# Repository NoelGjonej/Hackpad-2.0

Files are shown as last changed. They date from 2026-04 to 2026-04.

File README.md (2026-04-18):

# PCB Design



# Case Design



# XIAO Macropad — KMK Firmware
## Seeeduino XIAO · 6 Keys · EC11E Rotary Encoder · SSD1306 128x32 OLED

---

## Why KMK instead of QMK?

KMK runs on **CircuitPython** — there is no compiling, no toolchain, no flashing.
You just copy files onto the XIAO like a USB drive. Much easier for the XIAO.

---

## Key Layout

```
[ PREV  ] [ PLAY  ] [ NEXT  ]
[ COPY  ] [ PASTE ] [ SNIP  ]
                              Encoder CW  → Volume Up
                              Encoder CCW → Volume Down
                              Encoder Click → Mute / Unmute
```

| Key | Action |
|-----|---|
| Top-left  | ⏮ Previous Track |
| Top-mid | ▶ Play / Pause |
| Top-right | ⏭ Next Track |
| Bot-left  | Ctrl+C — Copy |
| Bot-mid | Ctrl+V — Paste |
| Bot-right | Win+Shift+S — Snipping Tool |
| Encoder CW | 🔊 Volume Up |
| Encoder CCW | 🔉 Volume Down |
| Encoder click | 🔇 Mute / Unmute toggle |

---

## Wiring

### Key Matrix (2 rows × 3 cols, COL2ROW diodes)

```
         COL0(D0)   COL1(D1)   COL2(D2)
ROW0(D3)   PREV       PLAY       NEXT
ROW1(D4)   COPY       PASTE      SNIP
```

Add a 1N4148 diode per switch — cathode (black band) toward the ROW pin.

### EC11E Encoder

| EC11E pin | XIAO pin | Function |
|---|---|---|
| CLK (A) | D7 | Rotation A |
| DT  (B) | D8 | Rotation B |
| SW | D6 | Click = Mute |
| GND | GND | Ground |

Add 10kΩ pull-up resistors on CLK and DT to 3.3V if you get jitter.

### SSD1306 OLED (I2C, 128×32)

| OLED pin | XIAO pin |
|---|---|
| SDA | D9  (SDA) |
| SCL | D10 (SCL) |
| VCC | 3.3V |
| GND | GND |

Default I2C address is 0x3C. If your OLED doesn't appear, try 0x3D in code.py.

---

## Setup Instructions

### Step 1 — Install CircuitPython on the XIAO

1. Download the CircuitPython UF2 for Seeeduino XIAO from:
   https://circuitpython.org/board/seeeduino_xiao/
   (download the latest stable .uf2 file)

2. Double-tap the RST pin on the XIAO — a drive called **XIAO-BOOT** appears on your PC.

3. Drag and drop the `.uf2` file onto that drive.
   The XIAO reboots and a new drive called **CIRCUITPY** appears.

### Step 2 — Install CircuitPython libraries

Download the CircuitPython Library Bundle from:
https://circuitpython.org/libraries

Unzip it. From the `lib/` folder inside, copy these folders/files
into the `lib/` folder on your **CIRCUITPY** drive:

```
adafruit_displayio_ssd1306.mpy
adafruit_display_text/
adafruit_imageload/
kmk/                          ← get this from https://github.com/KMKfw/kmk_firmware
```

To get KMK, download the zip from https://github.com/KMKfw/kmk_firmware
and copy the `kmk/` folder onto CIRCUITPY/lib/.

### Step 3 — Copy your code

Copy these two files from this folder onto the root of **CIRCUITPY**:

```
boot.py   → CIRCUITPY/boot.py
code.py   → CIRCUITPY/code.py
```

Your CIRCUITPY drive should look like:
```
CIRCUITPY/
├── boot.py
├── code.py
└── lib/
    ├── kmk/
    ├── adafruit_displayio_ssd1306.mpy
    ├── adafruit_display_text/
    └── adafruit_imageload/
```

### Step 4 — Done

The XIAO reboots automatically when you save files. Your macropad is ready.
No compiling, no flashing tools needed.

---

## Making changes

To change a key, open `code.py` in any text editor, edit the `keyboard.keymap` list,
and save. The XIAO reboots and picks up the change in a few seconds.

Common keycodes:
```python
KC.LCTL(KC.Z)     # Ctrl+Z  (undo)
KC.LCTL(KC.S)     # Ctrl+S  (save)
KC.LGUI(KC.L)     # Win+L   (lock screen)
KC.PSCR           # Print Screen
KC.TAB, KC.ESC, KC.ENT, KC.BSPC
KC.F1 ... KC.F12
```

---

## Troubleshooting

| Problem | Fix |
|---|-----|
| CIRCUITPY drive doesn't appear | Double-tap RST faster (within ~500ms) |
| Keys not working | Check diode direction — cathode (black band) toward row pin |
| Encoder jittery | Add 10kΩ pull-ups on CLK and DT to 3.3V |
| OLED blank | Check SDA/SCL wiring; try changing 0x3C to 0x3D in code.py |
| Error on boot | Connect to XIAO via serial (PuTTY / Thonny) to read the error message |

### Reading error messages (very useful for debugging)

Install **Thonny** (free Python IDE): https://thonny.org
Connect to the XIAO's serial port — it shows any Python errors live,
which makes debugging very easy.

---

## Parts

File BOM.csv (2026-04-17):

Name | Purpose | Quantity
0.91" display | Display volume | 1
XIAO RP2040 | Controll everything | 1
EC11E Rotary Encoder | Controll volume | 1
Key Switch | Skip/Play etc. | 6

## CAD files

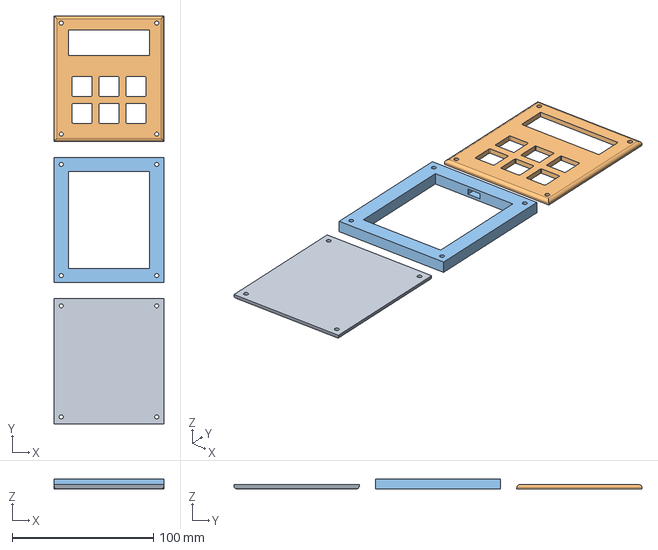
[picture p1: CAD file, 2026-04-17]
Hackpad 2.0.step
77.5 x 288.6 x 7.00 mm

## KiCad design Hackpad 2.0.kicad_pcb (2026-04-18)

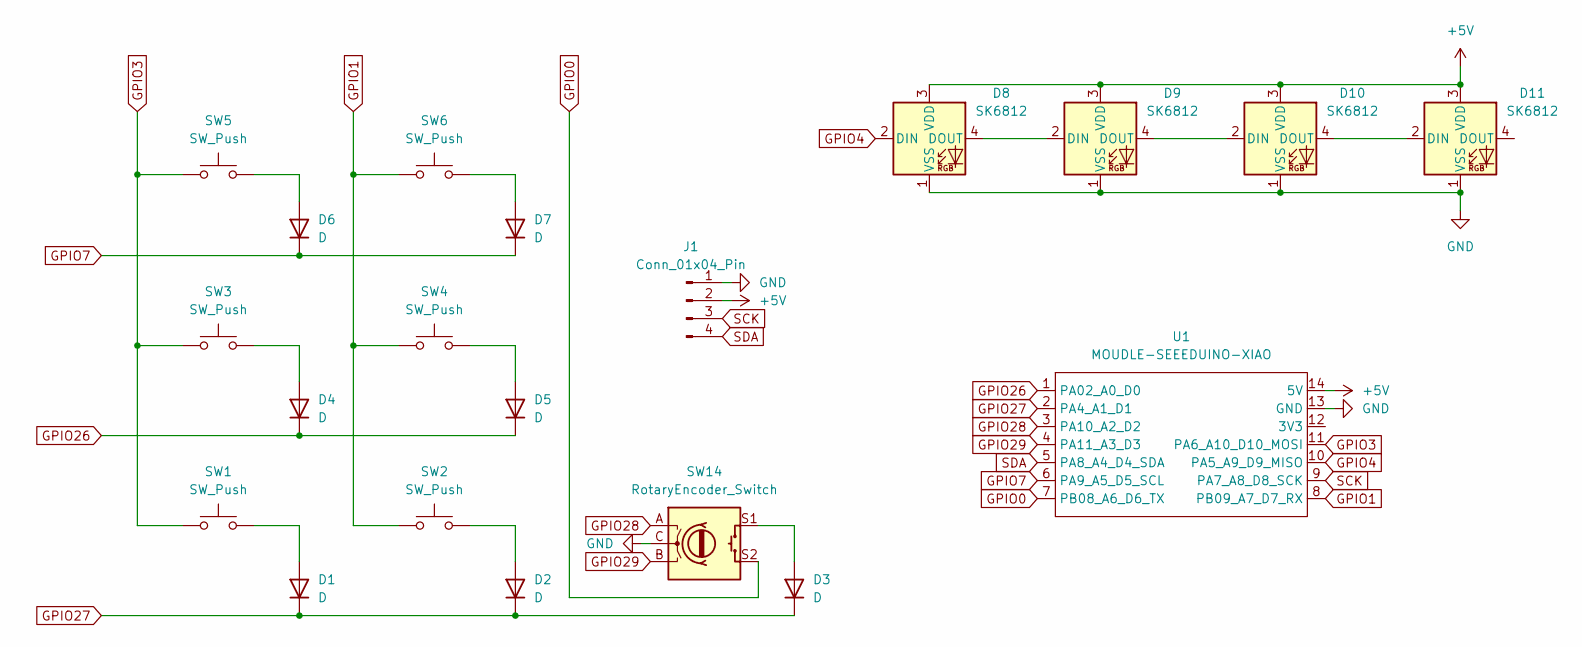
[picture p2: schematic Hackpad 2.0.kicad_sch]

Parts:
D1, D2, D3, D4, D5, D6, D7: D; D_DO-35_SOD27_P7.62mm_Horizontal
D8, D9, D10, D11: SK6812; LED_SK6812_PLCC4_5.0x5.0mm_P3.2mm
J1: Conn_01x04_Pin; PinSocket_1x04_P2.54mm_Vertical
SW1, SW2, SW3, SW4, SW5, SW6: SW_Push; SW_Cherry_MX_1.00u_PCB
SW14: RotaryEncoder_Switch; RotaryEncoder_Alps_EC11E-Switch_Vertical_H20mm
U1: MOUDLE-SEEEDUINO-XIAO; XIAO-Generic-Hybrid-14P-2.54-21X17.8MM

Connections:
+5V: D8.3 (VDD), D9.3 (VDD), D10.3 (VDD), D11.3 (VDD), J1.2, U1.14 (5V)
GND: D8.1 (VSS), D9.1 (VSS), D10.1 (VSS), D11.1 (VSS), J1.1, SW14.C, U1.13 (GND)
GPIO0: SW14.S2, U1.7 (PB08_A6_D6_TX)
GPIO1: SW2.1, SW4.1, SW6.1, U1.8 (PB09_A7_D7_RX)
GPIO3: SW1.1, SW3.1, SW5.1, U1.11 (PA6_A10_D10_MOSI)
GPIO4: D8.2 (DIN), U1.10 (PA5_A9_D9_MISO)
GPIO7: D6.1 (K), D7.1 (K), U1.6 (PA9_A5_D5_SCL)
GPIO26: D4.1 (K), D5.1 (K), U1.1 (PA02_A0_D0)
GPIO27: D1.1 (K), D2.1 (K), D3.1 (K), U1.2 (PA4_A1_D1)
GPIO28: SW14.A, U1.3 (PA10_A2_D2)
GPIO29: SW14.B, U1.4 (PA11_A3_D3)
unnamed: D1.2 (A), SW1.2
unnamed: D2.2 (A), SW2.2
unnamed: D3.2 (A), SW14.S1
unnamed: D4.2 (A), SW3.2
unnamed: D5.2 (A), SW4.2
unnamed: D6.2 (A), SW5.2
unnamed: D7.2 (A), SW6.2
unnamed: D8.4 (DOUT), D9.2 (DIN)
unnamed: D9.4 (DOUT), D10.2 (DIN)
unnamed: D10.4 (DOUT), D11.2 (DIN)
SCK: J1.3, U1.9 (PA7_A8_D8_SCK)
SDA: J1.4, U1.5 (PA8_A4_D4_SDA)

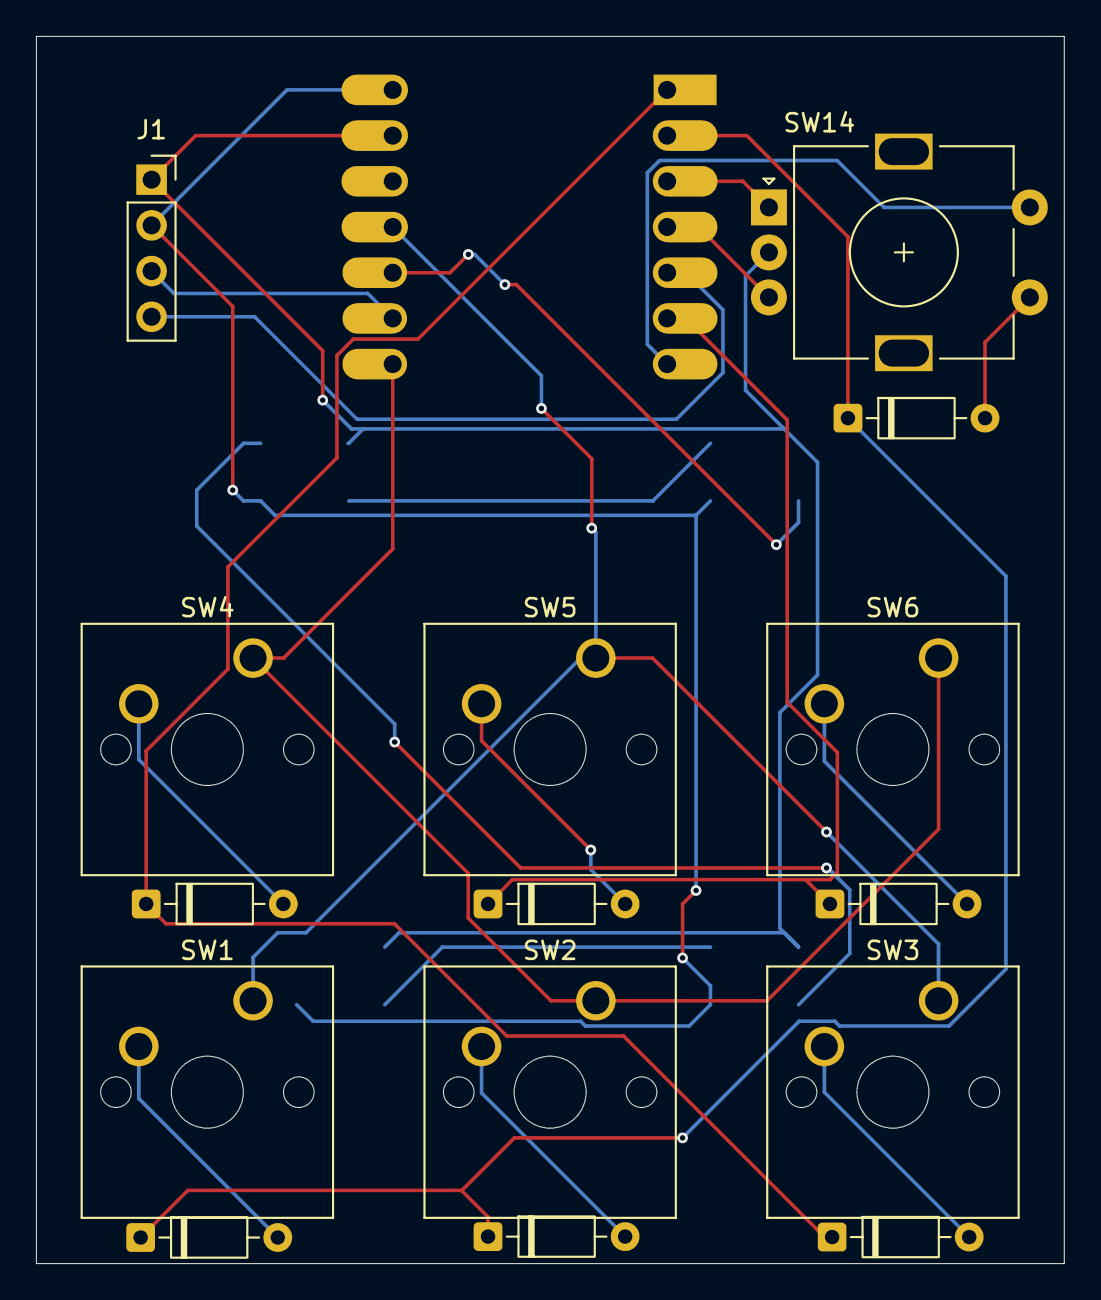
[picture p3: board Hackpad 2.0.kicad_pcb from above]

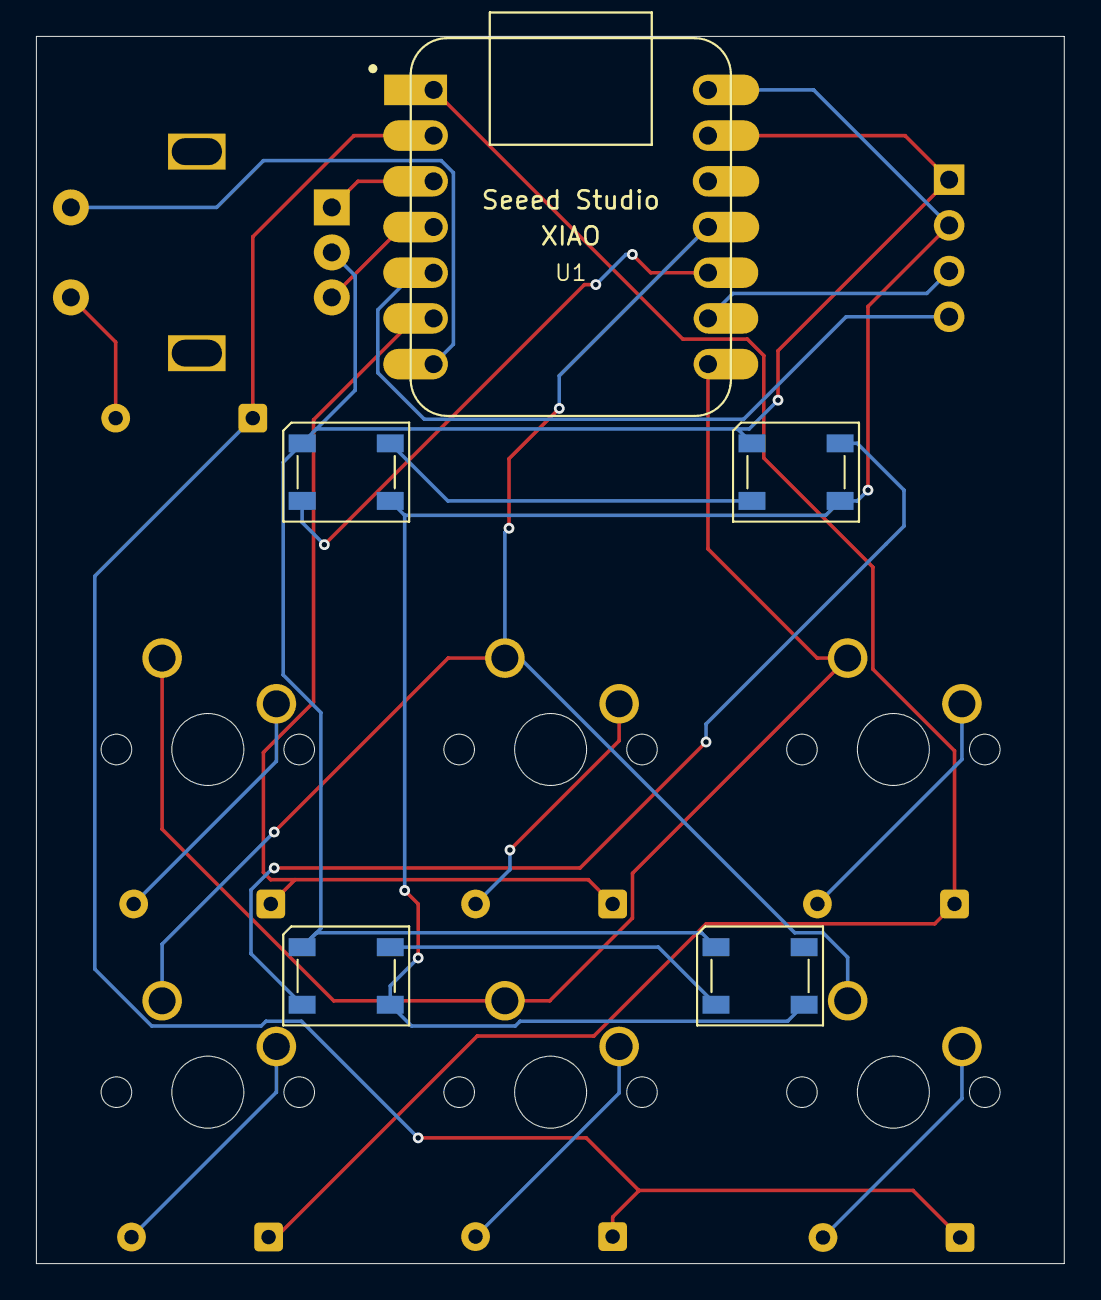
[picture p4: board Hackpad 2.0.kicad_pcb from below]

Board: 2 copper layers, 57.1 x 68.2 mm, 20 parts (5 on the bottom side), 23 nets.

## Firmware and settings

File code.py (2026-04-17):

import board
import busio
import digitalio
import rotaryio
import usb_hid
import time

from kmk.kmk_keyboard import KMKKeyboard
from kmk.keys import KC
from kmk.scanners import DiodeOrientation
from kmk.modules.encoder import EncoderHandler
from kmk.extensions.media_keys import MediaKeys

# ── OLED (SSD1306 128x32 via I2C) ────────────────────────────────────────────
import displayio
import terminalio
import adafruit_displayio_ssd1306
from adafruit_display_text import label
import adafruit_imageload

displayio.release_displays()

i2c = busio.I2C(scl=board.SCL, sda=board.SDA)
display_bus = displayio.I2CDisplay(i2c, device_address=0x3C)
display = adafruit_displayio_ssd1306.SSD1306(display_bus, width=128, height=32)

# ── Volume state ──────────────────────────────────────────────────────────────
vol_level  = 50    # local display counter 0–100
is_muted   = False

# ── Build the OLED UI ─────────────────────────────────────────────────────────
splash = displayio.Group()
display.show(splash)

# Line 0 — title
title_label = label.Label(terminalio.FONT, text="  XIAO Macropad ", x=0, y=4, color=0xFFFFFF)
splash.append(title_label)

# Line 1 — vol or mute text
vol_label = label.Label(terminalio.FONT, text=" VOL:  50%       ", x=0, y=14, color=0xFFFFFF)
splash.append(vol_label)

# Line 2 — bar background (dark rectangle)
bar_bg = displayio.Bitmap(128, 7, 2)
bar_bg_palette = displayio.Palette(2)
bar_bg_palette[0] = 0x000000
bar_bg_palette[1] = 0x444444
for x in range(128):
    for y in range(7):
        bar_bg[x, y] = 1
bar_bg_sprite = displayio.TileGrid(bar_bg, pixel_shader=bar_bg_palette, x=0, y=22)
splash.append(bar_bg_sprite)

# Line 2 — bar fill (white, width changes with volume)
bar_fill = displayio.Bitmap(128, 7, 2)
bar_fill_palette = displayio.Palette(2)
bar_fill_palette[0] = 0x000000
bar_fill_palette[1] = 0xFFFFFF
bar_fill_sprite = displayio.TileGrid(bar_fill, pixel_shader=bar_fill_palette, x=0, y=22)
splash.append(bar_fill_sprite)

def update_bar(percent):
    """Fill the bar bitmap proportionally to percent (0–100)."""
    filled_px = int((percent / 100) * 128)
    for x in range(128):
        for y in range(7):
            bar_fill[x, y] = 1 if x < filled_px else 0

def update_oled():
    """Refresh all OLED elements from current state."""
    global vol_level, is_muted
    if is_muted:
        vol_label.text = "   >> MUTED <<   "
        update_bar(0)
    else:
        vol_label.text = " VOL: {:3d}%       ".format(vol_level)
        update_bar(vol_level)

update_oled()

# ── Keyboard setup ────────────────────────────────────────────────────────────
keyboard = KMKKeyboard()
keyboard.extensions.append(MediaKeys())

# Matrix pins — 2 rows x 3 cols
keyboard.col_pins = (board.D0, board.D1, board.D2)
keyboard.row_pins = (board.D3, board.D4)
keyboard.diode_orientation = DiodeOrientation.COL2ROW

# ── Encoder ───────────────────────────────────────────────────────────────────
encoder_handler = EncoderHandler()
encoder_handler.pins = ((board.D7, board.D8, board.D6, False),)
# D7 = CLK (A), D8 = DT (B), D6 = push button, False = not inverted
keyboard.modules.append(encoder_handler)

# ── Snipping Tool macro (Win+Shift+S) ─────────────────────────────────────────
SNIP = KC.LGUI(KC.LSFT(KC.S))

# ── Mute toggle key (encoder click) ───────────────────────────────────────────
# We use a custom key that also flips our OLED state
def mute_press(key, keyboard, *args):
    global is_muted
    is_muted = not is_muted
    update_oled()
    # Also send the real OS mute keycode
    keyboard.tap_key(KC.MUTE)

ENC_MUTE = KC.make_key(on_press=mute_press)

# ── Keymap ────────────────────────────────────────────────────────────────────
#
#   [ PREV ] [ PLAY ] [ NEXT ]
#   [ COPY ] [PASTE ] [ SNIP ]
#                               Encoder: CW=Vol Up | CCW=Vol Down | Click=Mute
#
keyboard.keymap = [
    [
        KC.MPRV,   KC.MPLY,   KC.MNXT,   # Row 0: Prev | Play/Pause | Next
        KC.LCTL(KC.C), KC.LCTL(KC.V), SNIP,  # Row 1: Copy | Paste | Snip
    ]
]

# ── Encoder map ───────────────────────────────────────────────────────────────
# Format: ((CW_key, CCW_key, click_key), ...)  per layer
encoder_handler.map = [
    ((KC.VOLU, KC.VOLD, ENC_MUTE),),  # Layer 0
]

# ── Encoder vol tracking hook ─────────────────────────────────────────────────
# Wrap the encoder handler to also update our display counter
_orig_encoder = encoder_handler.during_bootup

def _on_encoder(key, keyboard, *args):
    global vol_level, is_muted
    if key == KC.VOLU:
        if vol_level < 100:
            vol_level += 1
        if is_muted:               # turning up while muted = unmute
            is_muted = False
    elif key == KC.VOLD:
        if vol_level > 0:
            vol_level -= 1
    update_oled()

# Patch volume keys to also update OLED
KC.VOLU.before_press_handler(_on_encoder)
KC.VOLD.before_press_handler(_on_encoder)

# ── Run ───────────────────────────────────────────────────────────────────────
if __name__ == "__main__":
    keyboard.go()

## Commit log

2026-04-17 Update README with PCB and Case design sections
    Added sections for PCB and Case design with images.
2026-04-18 Update image in PCB Design section of README
